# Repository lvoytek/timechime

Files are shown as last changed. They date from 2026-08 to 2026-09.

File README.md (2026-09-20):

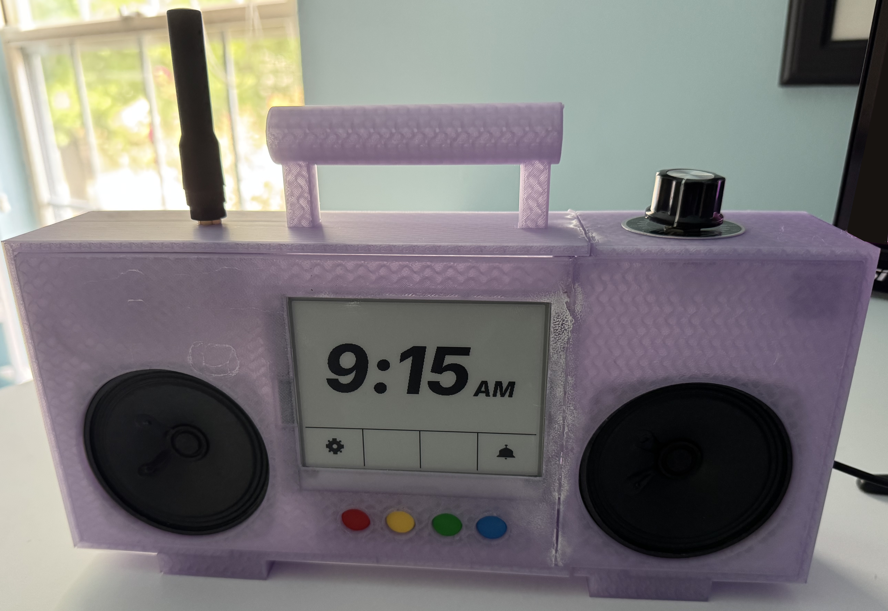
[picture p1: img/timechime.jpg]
TimeChime


# TimeChime
Daily alarm clock system with e-Paper display.

## Software
* [Zephyr RTOS](https://docs.zephyrproject.org/latest/index.html)
* [Inter font](https://rsms.me/inter/)

## Hardware
* [Adafruit Feather m4 express](https://www.adafruit.com/product/3857)
* [Adafruit GPS Featherwing](https://www.adafruit.com/product/3133)
* [Adafruit Music Maker Featherwing](https://www.adafruit.com/product/3436)
* [Speakers x2](https://www.adafruit.com/product/1313)
* [Waveshare 4.2" e-Paper display](https://www.waveshare.com/4.2inch-e-paper-module.htm)
* [Buttons](https://www.adafruit.com/product/1009)
* SD Card
* Wire
* Micro-USB cable

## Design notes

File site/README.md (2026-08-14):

# Timechime configurator

Serve this webpage locally, such as with Python's http server

```bash
python3 -m http.server
```

Open the page on a Chromium-based browser, plug in the device, then connect with "Connect via WebUSB".

## Linux
Copy the timechime udev rules to allow WebUSB connection:

```bash
sudo cp site/99-timechime.rules /etc/udev/rules.d/
sudo udevadm control --reload
```

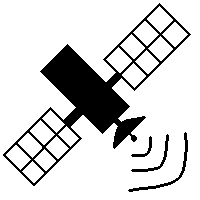
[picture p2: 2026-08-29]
sprites/gpssearch.bmp

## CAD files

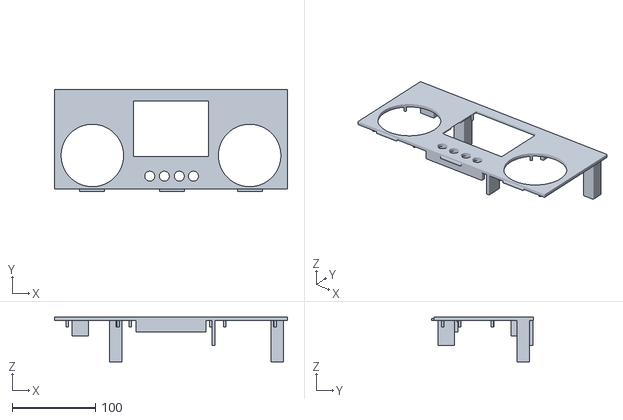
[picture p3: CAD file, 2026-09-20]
case/front.stl
280.0 x 123.0 x 54.0

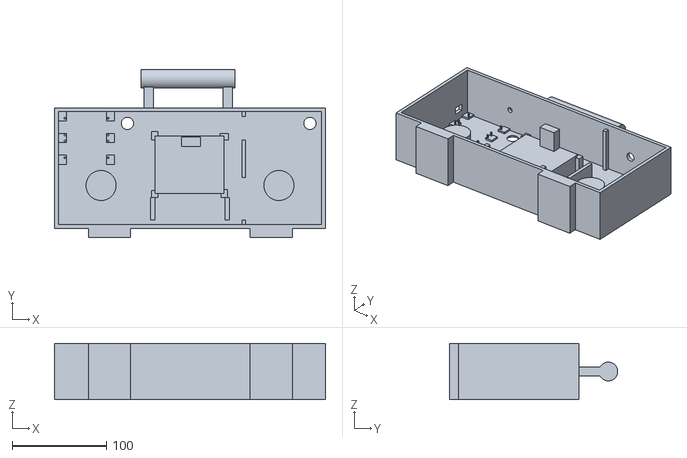
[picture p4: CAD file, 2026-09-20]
case/back.stl
288.0 x 179.0 x 60.0

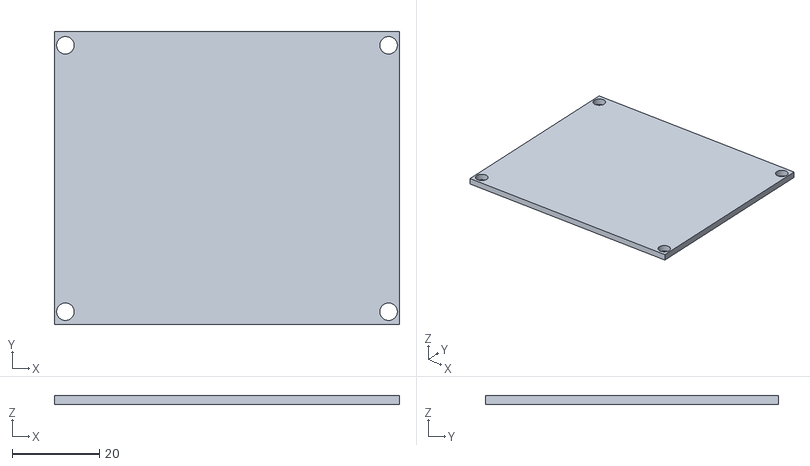
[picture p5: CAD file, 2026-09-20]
case/battery_cover.stl
79.0 x 67.0 x 2.00

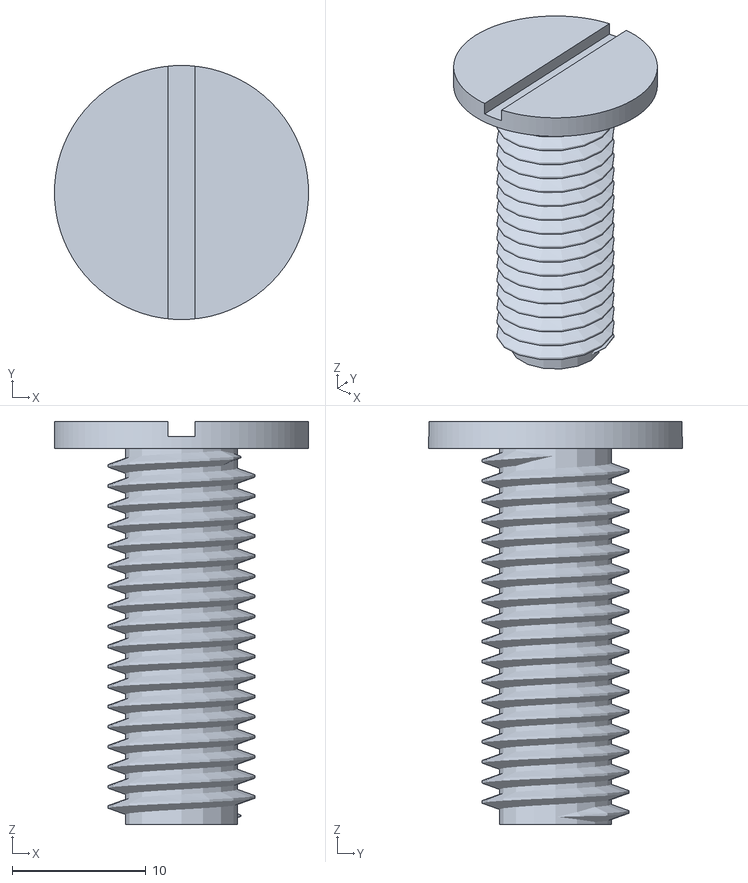
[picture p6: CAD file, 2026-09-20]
case/screw.stl
19.0 x 19.0 x 30.1

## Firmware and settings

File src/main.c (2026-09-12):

#include <zephyr/kernel.h>
#include <zephyr/fs/fs.h>
#include <ff.h>

#include "alarm.h"
#include "nav.h"
#include "pot.h"
#include "sound.h"
#include "time.h"
#include "usb.h"
#include "settings.h"

static FATFS fat_fs;
static struct fs_mount_t mp = {
	.type = FS_FATFS,
	.fs_data = &fat_fs,
	.mnt_point = "/SD:",
};

int main(void)
{
	fs_mount(&mp);

	timechime_usb_init();
	timechime_nav_init();
	timechime_alarm_init();
	timechime_pot_init();
	timechime_sound_init();
	timechime_time_load_preferences();

	while (1) {
		timechime_nav_update();
		timechime_alarm_update();
		timechime_sound_update();
		k_sleep(K_MSEC(100));
	}

	return 0;
}

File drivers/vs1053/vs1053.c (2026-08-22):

/*
 * VLSI VS1053b SPI audio DSP codec driver
 *
 * The VS1053b exposes two SPI interfaces on the same bus:
 *
 *   Serial Control Interface
 *     CS: XCS (active low, managed by the SPI bus driver via DT)
 *     Speed:       ~250kHz
 *     Protocol:    opcode[1] + addr[1] + data[2] for writes;
 *                  opcode[1] + addr[1] + dummy[2] + read[2] for reads
 *
 *   Serial Data Interface
 *     CS:          XDCS (active low, driven by dcs_gpio directly)
 *     Speed:       ~7.3MHz @ 3.3V
 *     Protocol:    raw compressed audio
 *
 * DREQ goes high when the chip can accept VS1053_SDI_CHUNK_SIZE more
 * bytes through the SDI.
 */

#define DT_DRV_COMPAT vlsi_vs1053

#include <zephyr/kernel.h>
#include <zephyr/drivers/gpio.h>
#include <zephyr/drivers/spi.h>
#include <zephyr/logging/log.h>

#include "vs1053.h"

LOG_MODULE_REGISTER(vs1053, CONFIG_LOG_DEFAULT_LEVEL);

// SPI command bytes
#define SCI_WRITE_CMD 0x02
#define SCI_READ_CMD  0x03

// Clock frequency: 3.5 x 12.288 MHz = ~43 MHz
#define CLOCKF_INIT 0x6000

// Initial volume: -10 dBFS per channel (0x00 = max, 0xFF = off)
#define VOLUME_INIT 20U

#define DREQ_TIMEOUT_MS 100

struct vs1053_config {
	struct spi_dt_spec spi;         // SPI
	struct gpio_dt_spec dreq_gpio;  // DREQ input
	struct gpio_dt_spec dcs_gpio;   // XDCS output
	struct gpio_dt_spec reset_gpio; // XRESET output
	uint32_t sdi_max_freq;          // SDI clock rate from DT
};

// Mutex for serial data transfer
struct vs1053_data {
	struct k_mutex lock;
};

/* ---- SCI ---- */

int vs1053_sci_write(const struct device *dev, uint8_t addr, uint16_t data)
{
	const struct vs1053_config *cfg = dev->config;
	uint8_t buf[4] = {
		SCI_WRITE_CMD,
		addr,
		(uint8_t)(data >> 8),
		(uint8_t)(data & 0xFF),
	};
	const struct spi_buf tx_buf = {.buf = buf, .len = sizeof(buf)};
	const struct spi_buf_set tx = {.buffers = &tx_buf, .count = 1};

	return spi_write_dt(&cfg->spi, &tx);
}

int vs1053_sci_read(const struct device *dev, uint8_t addr, uint16_t *val)
{
	const struct vs1053_config *cfg = dev->config;
	uint8_t tx_data[4] = {SCI_READ_CMD, addr, 0x00, 0x00};
	uint8_t rx_data[4] = {0};
	const struct spi_buf tx_buf = {.buf = tx_data, .len = sizeof(tx_data)};
	const struct spi_buf rx_buf = {.buf = rx_data, .len = sizeof(rx_data)};
	const struct spi_buf_set tx = {.buffers = &tx_buf, .count = 1};
	const struct spi_buf_set rx = {.buffers = &rx_buf, .count = 1};
	int ret;

	ret = spi_transceive_dt(&cfg->spi, &tx, &rx);
	if (ret == 0) {
		*val = ((uint16_t)rx_data[2] << 8) | rx_data[3];
	}
	return ret;
}

/* ---- SDI ---- */

bool vs1053_ready_for_data(const struct device *dev)
{
	const struct vs1053_config *cfg = dev->config;

	return gpio_pin_get_dt(&cfg->dreq_gpio) > 0;
}

// Send one chunk (<= VS1053_SDI_CHUNK_SIZE bytes) over the SDI.
static int sdi_write_chunk(const struct device *dev, const uint8_t *buf, size_t len)
{
	const struct vs1053_config *cfg = dev->config;
	const struct spi_buf tx_buf = {.buf = (void *)buf, .len = len};
	const struct spi_buf_set tx = {.buffers = &tx_buf, .count = 1};

	const struct spi_config sdi_cfg = {
		.frequency = cfg->sdi_max_freq,
		.operation = SPI_OP_MODE_MASTER | SPI_TRANSFER_MSB | SPI_WORD_SET(8),
	};
	int ret;

	gpio_pin_set_dt(&cfg->dcs_gpio, 1); // assert XDCS
	ret = spi_write(cfg->spi.bus, &sdi_cfg, &tx);
	gpio_pin_set_dt(&cfg->dcs_gpio, 0); // deassert XDCS

	return ret;
}

int vs1053_sdi_write(const struct device *dev, const uint8_t *buf, size_t len)
{
	struct vs1053_data *data = dev->data;
	size_t offset = 0;
	int ret = 0;

	k_mutex_lock(&data->lock, K_FOREVER);

	while (offset < len) {
		size_t chunk = MIN(len - offset, (size_t)VS1053_SDI_CHUNK_SIZE);
		int64_t deadline = k_uptime_get() + DREQ_TIMEOUT_MS;

		while (!vs1053_ready_for_data(dev)) {
			if (k_uptime_get() >= deadline) {
				ret = -ETIMEDOUT;
				goto out;
			}
			k_yield();
		}

		ret = sdi_write_chunk(dev, buf + offset, chunk);
		if (ret < 0) {
			goto out;
		}
		offset += chunk;
	}

out:
	k_mutex_unlock(&data->lock);
	return ret;
}

/* ---- Helpers ---- */

int vs1053_set_volume(const struct device *dev, uint8_t left, uint8_t right)
{
	return vs1053_sci_write(dev, VS1053_REG_VOLUME, ((uint16_t)left << 8) | right);
}

int vs1053_decode_time(const struct device *dev, uint16_t *seconds)
{
	return vs1053_sci_read(dev, VS1053_REG_DECODETIME, seconds);
}

int vs1053_soft_reset(const struct device *dev)
{
	int ret;

	ret = vs1053_sci_write(dev, VS1053_REG_MODE, VS1053_MODE_SM_SDINEW | VS1053_MODE_SM_RESET);
	if (ret < 0) {
		return ret;
	}

	// Wait 100ms for reset to complete
	int64_t deadline = k_uptime_get() + 100;

	while (!vs1053_ready_for_data(dev)) {
		if (k_uptime_get() >= deadline) {
			return -ETIMEDOUT;
		}
		k_msleep(1);
	}

	return 0;
}

/* ---- Driver init ---- */

static int vs1053_init(const struct device *dev)
{
	const struct vs1053_config *cfg = dev->config;
	struct vs1053_data *data = dev->data;
	int ret;

	k_mutex_init(&data->lock);

	if (!spi_is_ready_dt(&cfg->spi)) {
		LOG_ERR("SPI bus not ready");
		return -ENODEV;
	}

	if (!gpio_is_ready_dt(&cfg->dreq_gpio)) {
		LOG_ERR("DREQ GPIO not ready");
		return -ENODEV;
	}

	if (!gpio_is_ready_dt(&cfg->dcs_gpio)) {
		LOG_ERR("DCS GPIO not ready");
		return -ENODEV;
	}

	ret = gpio_pin_configure_dt(&cfg->dreq_gpio, GPIO_INPUT);
	if (ret < 0) {
		LOG_ERR("Failed to configure DREQ GPIO: %d", ret);
		return ret;
	}

	ret = gpio_pin_configure_dt(&cfg->dcs_gpio, GPIO_OUTPUT_INACTIVE);
	if (ret < 0) {
		LOG_ERR("Failed to configure DCS GPIO: %d", ret);
		return ret;
	}

	if (cfg->reset_gpio.port != NULL) {
		if (!gpio_is_ready_dt(&cfg->reset_gpio)) {
			LOG_ERR("RESET GPIO not ready");
			return -ENODEV;
		}
		ret = gpio_pin_configure_dt(&cfg->reset_gpio, GPIO_OUTPUT_INACTIVE);
		if (ret < 0) {
			LOG_ERR("Failed to configure RESET GPIO: %d", ret);
			return ret;
		}

		// Assert and deassert reset
		gpio_pin_set_dt(&cfg->reset_gpio, 1);
		k_msleep(10);
		gpio_pin_set_dt(&cfg->reset_gpio, 0);
		k_msleep(10);
	}

	ret = vs1053_soft_reset(dev);
	if (ret < 0) {
		LOG_ERR("Soft reset failed: %d", ret);
		return ret;
	}

	// Boost internal clock
	ret = vs1053_sci_write(dev, VS1053_REG_CLOCKF, CLOCKF_INIT);
	if (ret < 0) {
		return ret;
	}

	ret = vs1053_set_volume(dev, VOLUME_INIT, VOLUME_INIT);
	if (ret < 0) {
		return ret;
	}

	// Check status version field to confirm chip is online
	uint16_t status;

	ret = vs1053_sci_read(dev, VS1053_REG_STATUS, &status);
	if (ret < 0) {
		LOG_ERR("Failed to read STATUS register: %d", ret);
		return ret;
	}
	uint8_t version = (status >> 4) & 0x0F;

	if (version != 4) {
		LOG_WRN("Unexpected VS10xx version %u (expected 4 for VS1053)", version);
	} else {
		LOG_DBG("VS1053 detected (version=%u)", version);
	}

	return 0;
}

/* ---- Init macro ---- */
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

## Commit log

2026-08-04 Map Arduino R3 and spi onto lora feather to connect e-paper display
2026-08-05 Add function to draw sprites in button indicator locations
2026-08-05 Add plus, bell, and gear sprites
2026-08-05 Add ability to draw button indicator set
2026-08-06 Add function to draw the current time in large font
2026-08-07 Add gnss overlay to board matching Uart
2026-08-07 Properly clear screen on UI reset
    [screen_ui.c]
2026-08-07 Add GPS-based current time functions
2026-08-07 Re-arrange screen wires to be adjacent
2026-08-08 Move button indicator outline drawing to its own function
2026-08-08 Position alarm entry using layer and invert on selected
    [screen_ui.c]
2026-08-08 Move button locations
2026-08-08 Add feather layout definitions to board
2026-08-09 Timezone setting test no longer needed
    [main.c]
2026-08-09 Add udev rules to allow webusb device on linux
2026-08-22 Create vs1053 driver module, will send to zephyr upstream later
2026-08-22 Add driver to cmake
2026-08-23 Use overlay for screen cs, fixing conflict with USB and sound
    [screen_ui.c]
2026-09-05 Reverse button order
2026-09-07 Add button list to time select screen and add next alarm state
2026-09-12 Add current getter for 24-hr hour
2026-09-12 Add ADC entry to board overlay
2026-09-12 Reverse button order again
2026-09-20 Add 3d case design
    [back.stl, battery_cover.stl, front.stl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]
2026-09-24 Avoid multiple refresh callback registers to LVGL
    [screen_ui.c]
